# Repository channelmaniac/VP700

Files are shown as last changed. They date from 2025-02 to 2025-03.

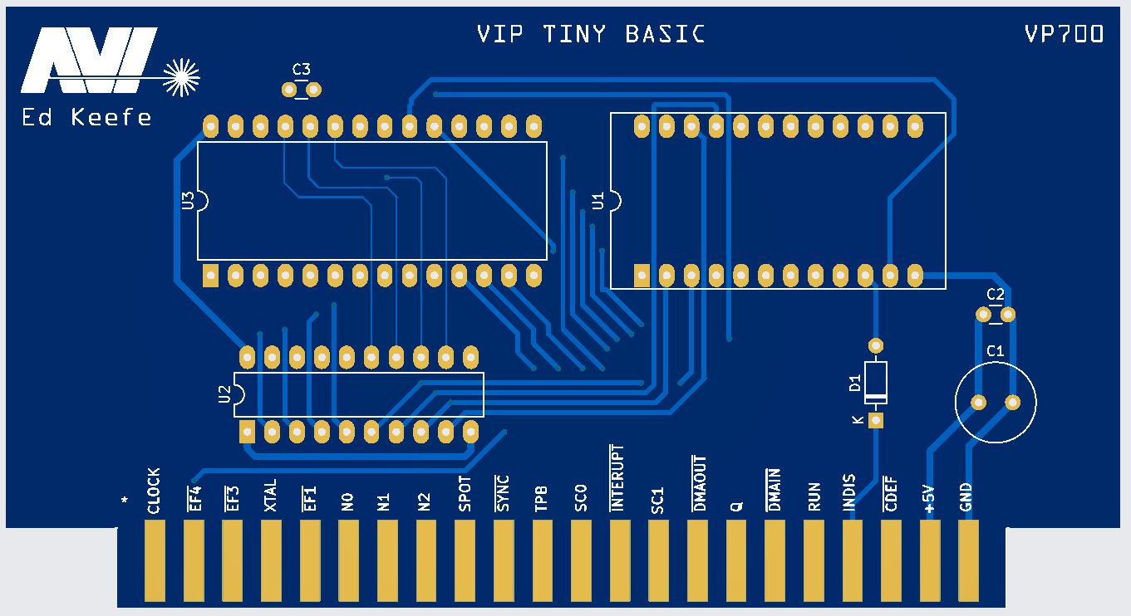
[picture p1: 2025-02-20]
VP700 Card.jpg

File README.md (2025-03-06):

# VP700
RCA VP700 Tiny BASIC Card

This was a project by the late Ed Keefe. He had dumped the VP700 Tiny BASIC card from RCA for the COSMAC VIP computer, reverse engineered the schematic from the board, and built a PCB to try and reproduce the card. The original can be seen on his web site at: https://www.cosmacvip.com/GALLERY/LARGEWM/IMG_2589.jpg

I was given a copy of the gerbers and had some PCBs made but could not get his PCB working. The problem boiled down to timing, address decoding, and which signals got used where. I figured out one part of it but was stuck getting it to boot immediately to the card after a reset of the CPU. Walter Miraglia was very helpful in working with me on this he engaged Josh Bensadon who figured out the issues, the proper connections for each part of the signalling, and that a tiny capacitor was needed to stretch a pulse on the /MRD (Memory Read) line.

Based on Josh's changes, I laid out a new card using Ed's logo like his had plus his name, which, additionally, I'd like to extend many thanks to Con Skordis for help with the 44 pin edge connector in KiCAD. With his permission I have added the edge connector files for KiCAD into the KiCAD Template directory here.

There are some difficulties in designing for this system. The address bus is multiplexed with the TPA signal used to define when the lower address bus information is available then when the upper address bus information is. The 8000 signal is a flipped version of the /8000 used to access the monitor ROM. When the 8000 signal is low, the lower half of memory is addressed. The lower half of memory is RAM and is incompletely decoded for access, resulting in mirrors at every 4K for the lower half of memory. The RAM can be disabled by asserting the MINH signal on the expansion bus, taking it to logic High. The Tiny BASIC card makes use of this.

The Tiny BASIC card represented some challenges as the Mask ROMs from RCA not only latch the address information internally, they also have internal address decoding so no external ICs for decoding addresses were necessary on that card. The 4516 CMOS chip is a 4 to 16 decoder and while it could be used to decode the addresses for the ROMs, it wasn't. It was used to decode the RAM address, disable the RAM from 0000-0FFF, and enable only the bank of RAM from 1000-1FFF using the MINH line. This is because the Tiny BASIC code sits at 0000-0FFF in memory and would otherwise conflict with the RAM. The diode on the MINH signal is because RCA specified a diode to be used on that signal line in documentation. To further the difficulty in understanding how this card works, the upper address lines are not used in order for inputs on the 4516. Instead of mapping the inputs D(A15), C(A14), B(A13), and A(A12) being used, RCA mapped them as D(A15), C(A13), B(A12), and A(A14). This means you must build a table to map the upper address lines to understand the outputs properly.

Lower Memory Map:  (NOTE: the upper half of memory exhibits the same mirroring behavior with the Monitor ROM.)

0000-03FF - Bank 0 RAM (2x 2114 RAM chips)

0400-07FF - Bank 1 RAM (2x 2114 RAM chips)

0800-0BFF - Bank 2 RAM (2x 2114 RAM chips)

0C00-0FFF - Bank 3 RAM (2x 2114 RAM chips)

1000-1FFF - Mirror of bank 0-3

2000-2FFF - Mirror of bank 0-3

3000-3FFF - Mirror of bank 0-3

4000-4FFF - Mirror of bank 0-3

5000-5FFF - Mirror of bank 0-3

6000-6FFF - Mirror of bank 0-3

7000-7FFF - Mirror of bank 0-3

This new card uses the 4516 to also decode the address for the EEPROM / EPROM used to hold the Tiny BASIC code to have it appear in memory from 0000-0FFF so the only additional chip needed is the 74HC573 to latch the
upper 8 address lines. The card calls for a single 28C256 but the upper address lines are grounded. You are only using the lower 4K. If a 28C256 can't be found, a simple 27C64 will work just fine.

A 74HCT573 Octal latch will also work if you have those on hand instead of a 74HC573. Additionally a 74HC574 or 74HCT574 octal flip-flop will also work if a 573 is hard to source. While 74LS/S/AS/etc. may work, those
are NOT recommended as they take too much current to drive the inputs. RCA calls out that you should use CMOS buffers to drive TTL loads on the expansion interface and this card does not use those.

Thanks to Walter Miraglia for the page scans of the RCA Tiny BASIC manual. I've put them together in a single PDF file and put them here to make things easy.

The Tiny BASIC ROM code is as simple as installing the EMMA 02 emulator and grabbing the VP700_Tiny_BASIC.bin file from it to program into your own IC.

The PCBs have been ordered through JLCPCB and verified by me before the files were uploaded to this repsitory.

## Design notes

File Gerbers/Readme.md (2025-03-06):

Here are the gerbers for having a PCB made by your favorite fab. I used JLCPCB for these and they came out perfect.

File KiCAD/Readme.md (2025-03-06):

These are the KiCAD files for the VP700 circuit board. Please let me know if you have any feedback.

Yes, there is only 1 .1uf cap on the PCB. This was just echoing how RCA did the original PCB back in the day
as it only had 1 .1uf cap on it.

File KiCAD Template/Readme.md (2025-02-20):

These are the files needed to do a 44 pin card edge connector in KiCAD. They are labeled on both sides with signal name on the silkscreen layer.

Many thanks to Con Skordis for the files and the help!

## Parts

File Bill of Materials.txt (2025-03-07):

Bill of Materials:

This will be short as the card is not complicated! Part numbers not included as I had all the
parts in my stash except for the HC573 which came from Mouser. I have an affinity to use 
Mouser for my parts needs as I live a 45 minute drive from them and get parts next day if I 
order early enough. 

Parts needed: 

1x MC14515 or equivalent 4-bit transpare latch/4-to-16 line decoder
1x 74HC573 Octal D-type latch with 3-state outputs
  OR 74HCT573 Ocal D-type latch with 3-state outputs
  OR 74HC574 Octal Edge-Triggered D-Type Flip-Flops with 3-state outputs
  OR 74HCT574 Octal Edge-Triggered D-Type Flip-Flops with 3-state outputs
1x 28C256 32K x 8 EEPROM 
  OR 28C64 8K x 8 EEPROM
  OR 27C64 8K x 8 EPROM
  OR 2764 8K x 8 EPROM
1x 1N914 / 1N4148 Diode
1x 18-22pf Ceramic (disk or MLCC) capacitor
1x 100nf / .1uf / 104 Ceramic (disk or MLCC) capacitor
1x 100uf Electrolytic capacitor
1x 24-pin .6" wide dual wipe socket
1x 24-pin .6" wide dual wipe socket
1x 20-pin dual wipe socket

To get the code for the EPROM/EEPROM, install the EMMA 02 emulator and pull the VP700_Tiny_BASIC.bin
file from the program's files.

And 1 of the PCBs from your favorite PCB manufacturer. I used JLCPCB.

Either the 74HC or HCT family latch will work for this. The important part is that either act as
CMOS inputs with low input current orf 1uA max to keep from being too much of a load to the VIP
which had 1 TTL load listed in the documentation. The outputs for either chip will drive up to 
"15 LSTTL loads" but are only driving the upper address lines to the EEPROM or EPROM being used.

The value of the timing bodge capacitor has been tested at 18pf with a ceramic 1802 CPU installed 
on the VIP and at 22pf with a plastic CPU installed on the VIP. The PCB was designed to use a 
28C256 with the upper address lines grounded. Smaller sized 28 pin devices will work and the 
28C64 and 2764 chips have been successfully tested.

At the slow CPU speeds of the 1802 in the VIP, slower cycle time EPROMs (300ns) have been tested
and should work fine. The 14515 used was from Motorola and the HC573 was from Texas Instruments. 
This should not matter and other manufacturer parts should work fine. Other families (LS, ALS, F,
H, S, etc.) of the HC573 have not been tested and should not be used as the VIP documentation 
specifies using CMOS. The documemtation states to use CMOS buffer chips if using TTL on the
expansion interface.

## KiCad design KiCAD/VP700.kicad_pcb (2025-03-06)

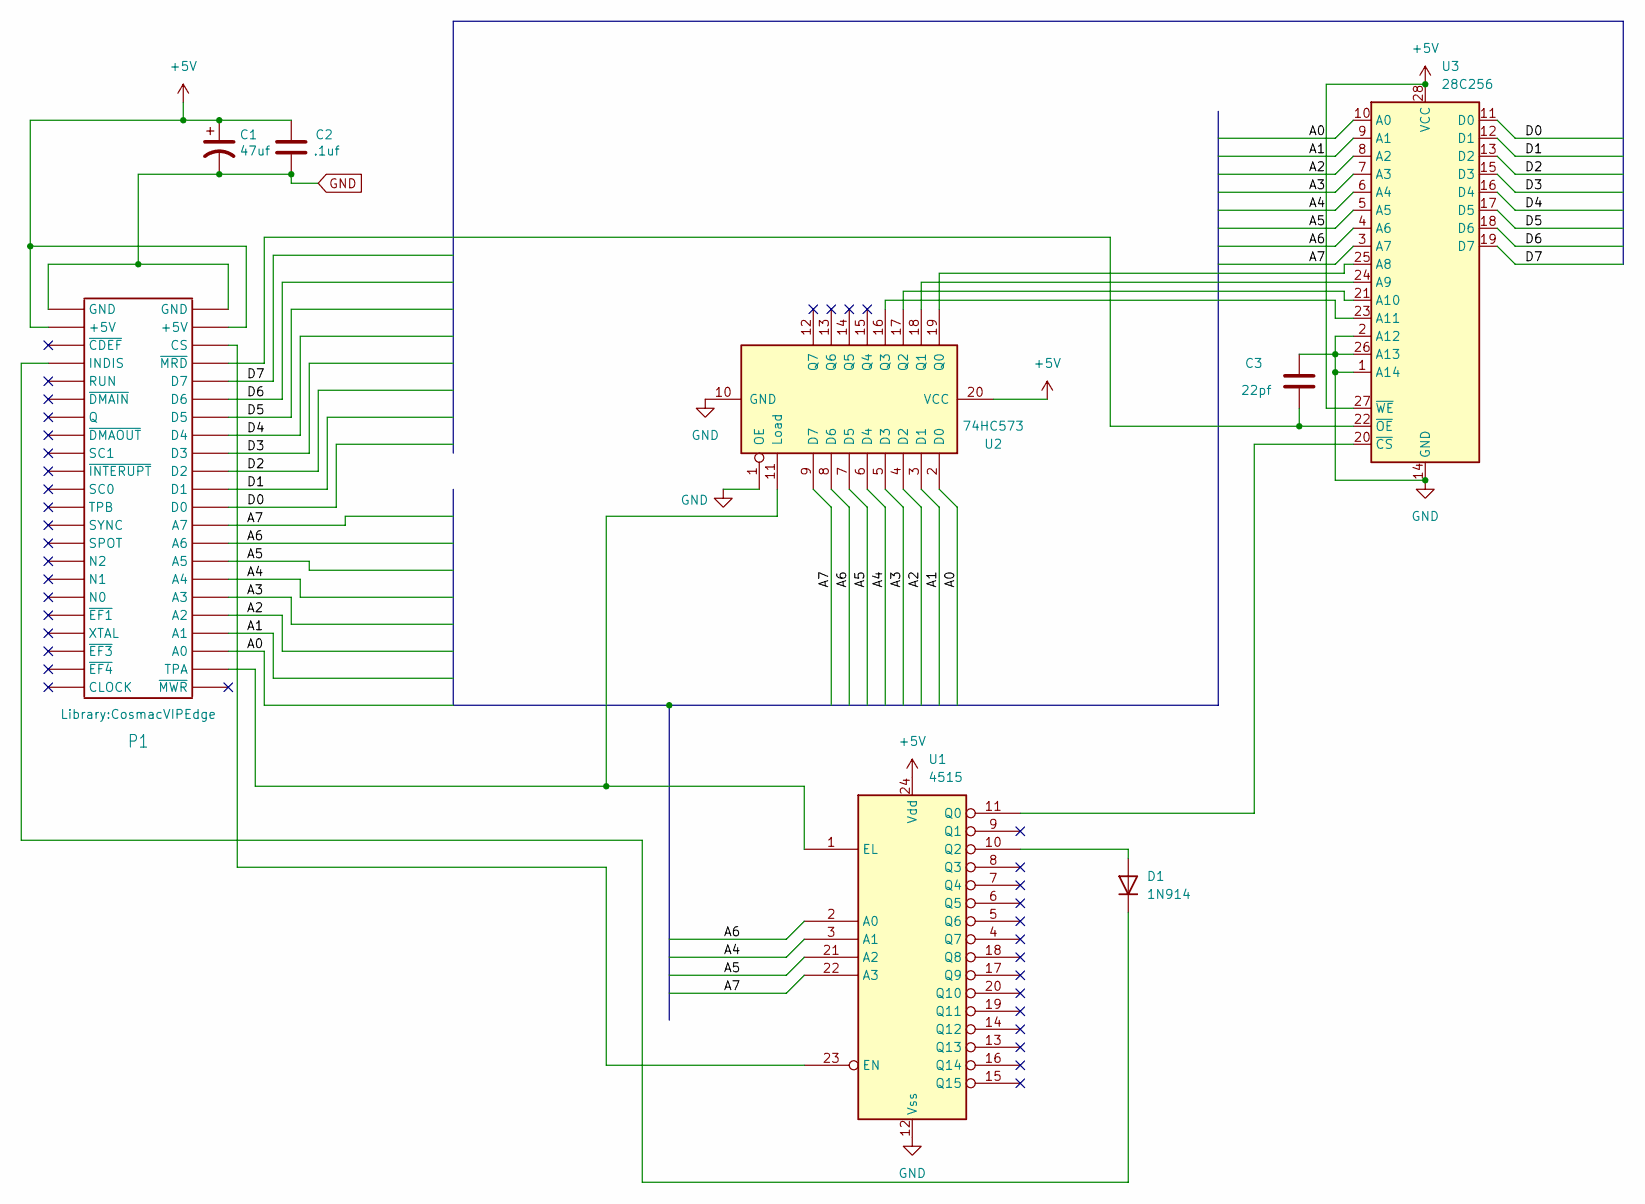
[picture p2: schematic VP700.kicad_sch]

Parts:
C1: 47uf; C_Radial_D8.0mm_H7.0mm_P3.50mm
C2: .1uf; C_Disc_D3.0mm_W1.6mm_P2.50mm
C3: 22pf; C_Disc_D3.0mm_W1.6mm_P2.50mm
D1: 1N914; D_DO-35_SOD27_P7.62mm_Horizontal
P1: Cosmac VIP Edge; CosmacVIPEdge
U1: 4515; DIP-24_18.0mmx34.29mm_W15.24mm_LongPads
U2: 74HC573; DIP-20_W7.62mm_LongPads
U3: 28C256; DIP-28_W15.24mm_LongPads

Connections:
+5V: C1.1, C2.1, P1.21 (+5V), P1.Y (+5V), U1.24 (Vdd), U2.20 (VCC), U3.27 (~WE), U3.28 (VCC)
/A0: P1.C (A0), U2.2 (D0), U3.10 (A0)
/A1: P1.D (A1), U2.3 (D1), U3.9 (A1)
/A2: P1.E (A2), U2.4 (D2), U3.8 (A2)
/A3: P1.F (A3), U2.5 (D3), U3.7 (A3)
/A4: P1.H (A4), U1.3 (A1), U2.6 (D4), U3.6 (A4)
/A5: P1.J (A5), U1.21 (A2), U2.7 (D5), U3.5 (A5)
/A6: P1.K (A6), U1.2 (A0), U2.8 (D6), U3.4 (A6)
/A7: P1.L (A7), U1.22 (A3), U2.9 (D7), U3.3 (A7)
/D0: P1.M (D0), U3.11 (D0)
/D1: P1.N (D1), U3.12 (D1)
/D2: P1.P (D2), U3.13 (D2)
/D3: P1.R (D3), U3.15 (D3)
/D4: P1.S (D4), U3.16 (D4)
/D5: P1.T (D5), U3.17 (D5)
/D6: P1.U (D6), U3.18 (D6)
/D7: P1.V (D7), U3.19 (D7)
GND: C1.2, C2.2, C3.1, P1.22 (GND), P1.Z (GND), U1.12 (Vss), U2.1 (OE), U2.10 (GND), U3.1 (A14), U3.2 (A12), U3.14 (GND), U3.26 (A13)
unnamed: D1.2 (A), U1.10 (Q2)
unnamed: D1.1 (K), P1.19 (INDIS)
unnamed: P1.X (CS), U1.23 (EN)
unnamed: P1.B (TPA), U1.1 (EL), U2.11 (Load)
unnamed: C3.2, P1.W (~MRD), U3.22 (~OE)
unnamed: U1.11 (Q0), U3.20 (~CS)
unnamed: U2.19 (Q0), U3.25 (A8)
unnamed: U2.18 (Q1), U3.24 (A9)
unnamed: U2.17 (Q2), U3.21 (A10)
unnamed: U2.16 (Q3), U3.23 (A11)

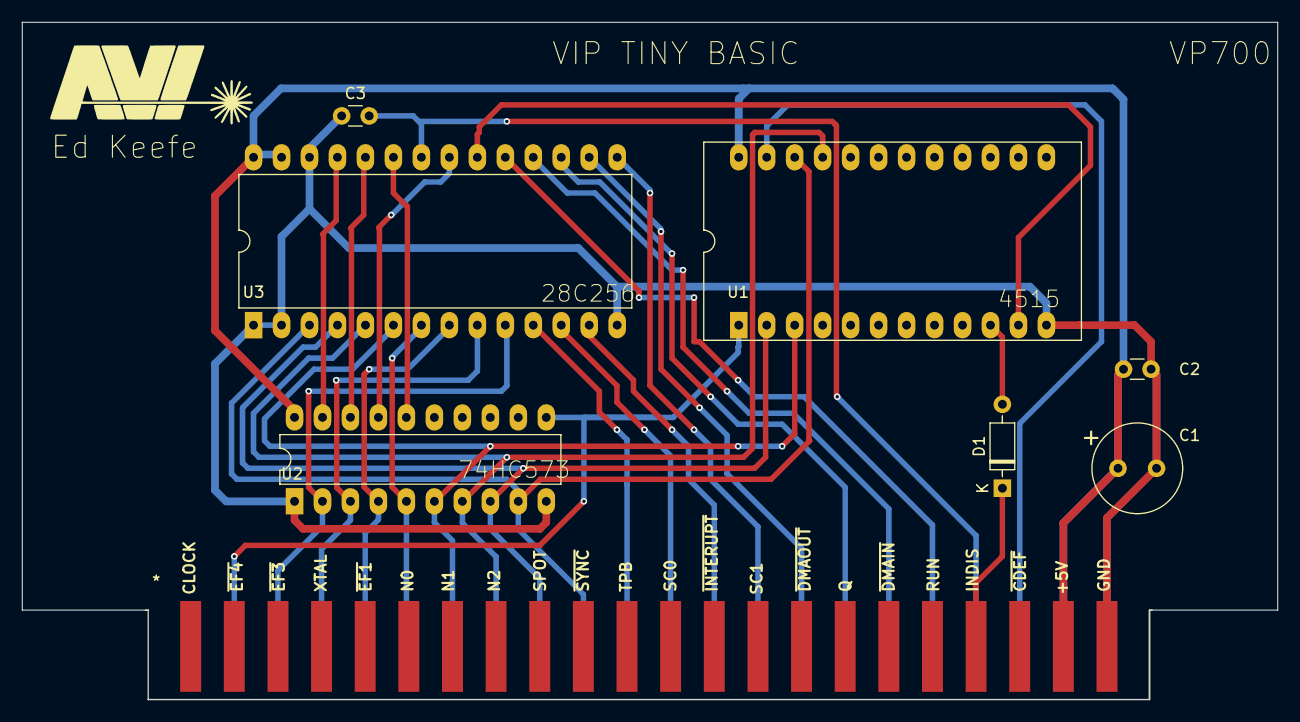
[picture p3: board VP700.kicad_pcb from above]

Board: 2 copper layers, 114.0 x 61.5 mm, 8 parts (0 on the bottom side), 28 nets.

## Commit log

2025-02-20 Add files via upload
    Add gerber view of the card and manual for Tiny BASIC
2025-02-20 Add files via upload
    Add KiCAD files
2025-02-26 Create Bill of Materials.txt
2025-02-26 Update Bill of Materials.txt
    Add in the diode...
2025-03-04 Update Bill of Materials.txt
    74HCT573 added.
2025-03-06 Update Bill of Materials.txt
    Add in another chip option
2025-03-06 Update Bill of Materials.txt
